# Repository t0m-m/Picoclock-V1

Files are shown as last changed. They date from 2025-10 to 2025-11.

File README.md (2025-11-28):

# Picoclock-V1

Simple desktop clock built around the Raspberry Pi Pico and a custom PCB.

# Overview

Picoclock-V1 is a prototype designed for feature testing.
The final version will showcase vintage VQB-71 7-segment displays, but all other elements will remain the same.

The board includes:

* DS3231 high-accuracy real-time clock

* MAX7221 display driver

* Buzzer for alarm

* Four control buttons for brightness, confirm, cancel, and mode selection

Currently, the unit does not include an onboard battery and requires external power via the Pico’s micro-USB port.
A future version may include a Li-ion battery pack for standalone operation.

# Implemented Features

* Time keeping

* Date display mode

* Alarm mode

* Hardware

Initially planned as a 2-layer PCB, the design evolved into a 4-layer board for cleaner signal routing and improved performance.
The board also includes four 3 mm mounting holes for attaching a plexiglass cover or securing the unit in place.

# Notes

This version focuses on functionality and layout validation. The next iteration will aim for improved aesthetics, enclosure design, and power management.



# Update - 12.11.2025

Boards and components finally arrived! Multimeter testing came out very promising. Soldering soon.



# Update 24.11.2025

Unfortunately there has been a mistake in the board files, the pins for the SPI were routed incorrectly. Luckily I have managed to fix the issue with external cables. I have updated the board files to the correct version. Below is the picture of working board. I am working on software, but basic functionality has been implemented.



https://github.com/user-attachments/assets/9fb4b469-f7aa-4e1a-90d6-b6b4e3de2fa9

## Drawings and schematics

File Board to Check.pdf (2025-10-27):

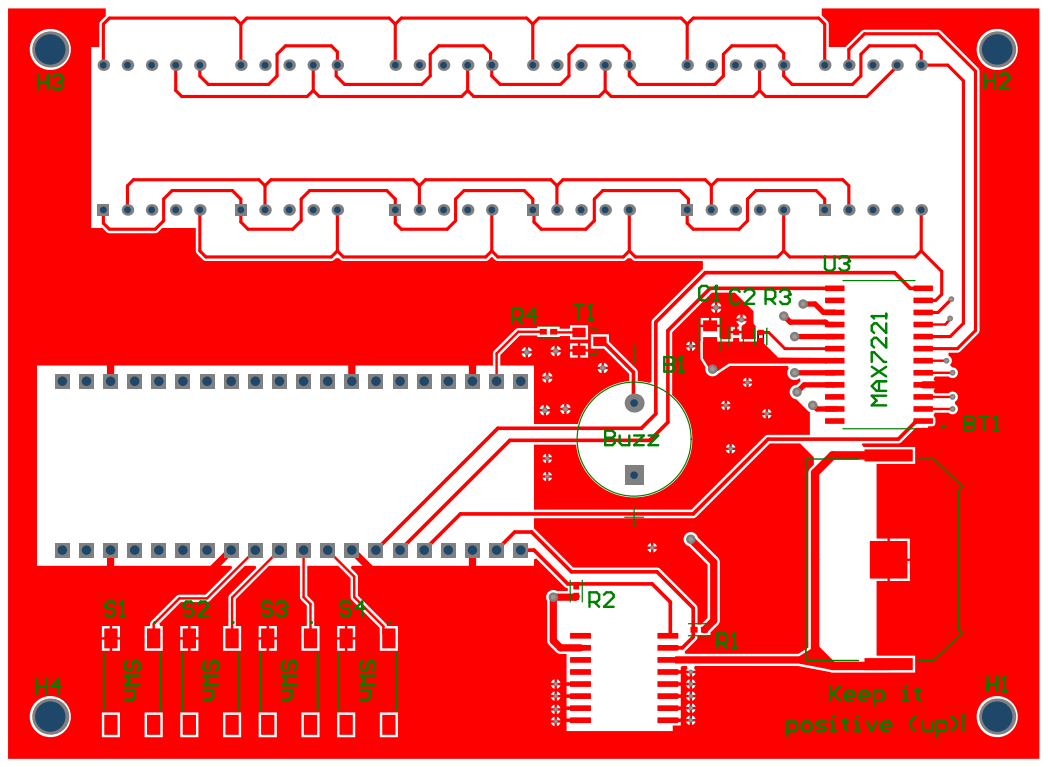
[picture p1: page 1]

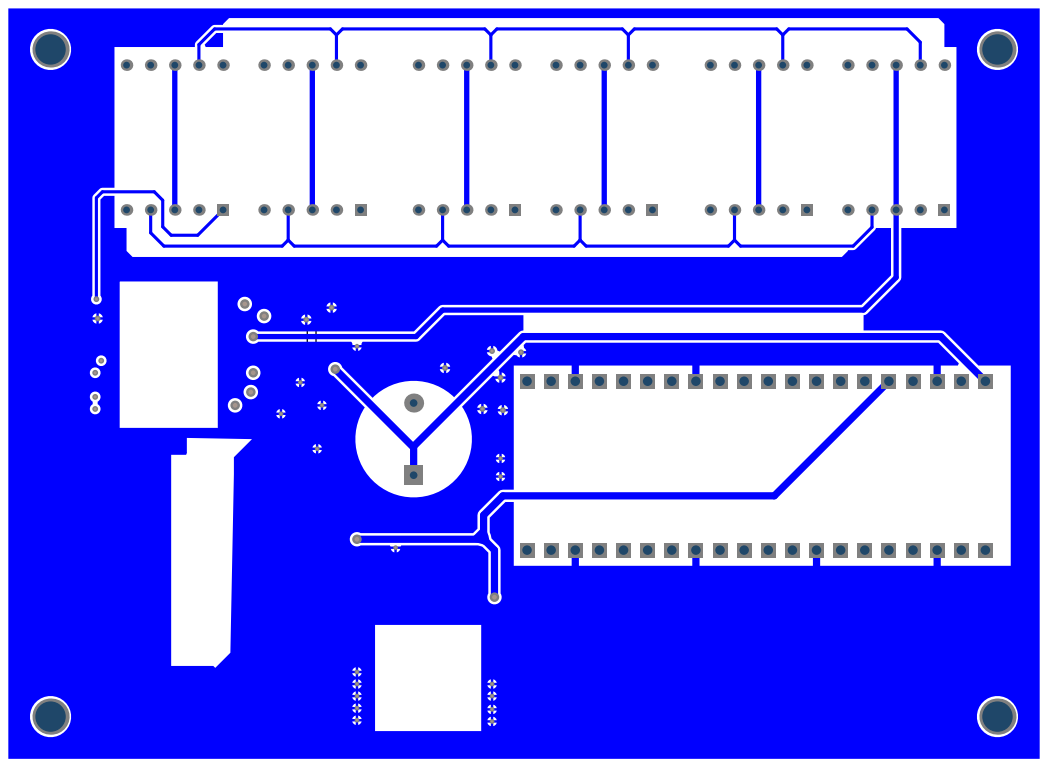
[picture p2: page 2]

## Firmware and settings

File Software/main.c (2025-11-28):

#include <stdio.h>
#include "pico/stdlib.h"
#include "hardware/spi.h"
#include "hardware/timer.h"
#include "hardware/i2c.h"
#include "pico/binary_info.h"

// PINY SPI
#define PIN_CS   13
#define PIN_SCK  10
#define PIN_MOSI 11

// PINY I2C
#define PIN_SDA 14
#define PIN_SCL 15

// PINY PRZYCISKOW
#define BUTTON_PIN 6
#define BUTTON_PIN2 7
#define BUTTON_PIN3 8
#define BUTTON_PIN4 9

// MAX 7221 
//void max7221_send(uint8_t addr, uint8_t data) {   // MAX oczekuje danych, 8 bitow adresu i 8 bitow danych
//    gpio_put(PIN_CS, 0);                          // aktywujemy CS, zeby MAX wiedzial ze do niego wysylamy, CS = 0 <- wysylamy, CS = 1 <- MAX przestaje odbierac i wykonuje komende
//    uint8_t buf[2] = { addr, data };              // 16 bitow, adres + data
//    spi_write_blocking(spi1, buf, 2);             // po sp1 wyslij z tablicy buf 2 wartosci pod kolejnymi jej adresami. blocking oznacza ze czeka az wszystkie dane zostana wyslane
//   gpio_put(PIN_CS, 1);                          // ustawiamy CS na wartosc 1, zeby MAX wykonal polecenia ktore mu dalismy
//}

//void max7221_init() {
//    max7221_send(0x09, 0x00);  // decode off
//    max7221_send(0x0A, 0x05);  // intensity
//    max7221_send(0x0B, 0x07);  // scan limit = 6
//    max7221_send(0x0C, 0x01);  // normal operation
//    max7221_send(0x0F, 0x00);  // display test off
//}

// I2C ADDRESS RESERVATION
bool reserved_addr(uint8_t addr) {                        // Funkcja sprawdza czy specjalne adresy i2c nie sa zarezerwowane 
    return (addr & 0x78) == 0 || (addr & 0x78) == 0x78;   // Specjalne adresy sa od 000 0xxx do 111 1xxx
}

// DS 3231
void ds3231_set_time(uint8_t *buf) {
    uint8_t start = 0x00; 
    i2c_write_blocking(i2c1, 0x68, &start, 1, true);
    i2c_write_blocking(i2c1, 0x68, buf, 7, false);
}

void ds3231_read_time(uint8_t *buf) {
    uint8_t start = 0x00;                                // 0x68 to adres i2c urzadzenia DS3231
    i2c_write_blocking(i2c1, 0x68, &start, 1, true);     // Funkcja ustawia bajt od ktorego chce czytac na 1
    i2c_read_blocking(i2c1, 0x68, buf, 7, false);        // Funkcja zczytuje wartości od 0x00 do 0x06, czyli sekundy, minuty, godziny, dzien tygodnia, dzien miesiaca, miesiac, rok 
}

void ds3231_init() {
    uint8_t EOSC = 0x0E;
    uint8_t reg;

    i2c_write_blocking(i2c1, 0x68, &EOSC, 1, true);
    i2c_read_blocking(i2c1, 0x68, &reg, 1, false);

    reg &= 0b00111111;

    i2c_write_blocking(i2c1, 0x68, &EOSC, 1, true);
    i2c_write_blocking(i2c1, 0x68, &reg, 1, false);
}

int bcd_to_int(uint8_t bcd) {                           // Funkcja ktora zamiaenia BCD na integer
    return ((bcd >> 4) * 10) + (bcd & 0x0F);            
}

// MAPA SEGMENTOW
// Segmenty: C DP A F G E D B   (nie wiem co tu sie odjebalo ale tak jest)
//const bool digit_segments[10][8] = {
//    {1,0,1,1,0,1,1,1}, // 0
//    {1,0,0,0,0,0,0,1}, // 1
//    {0,0,1,0,1,1,1,1}, // 2
//    {1,0,1,0,1,0,1,1}, // 3
//    {1,0,0,1,1,0,0,1}, // 4
//    {1,0,1,1,1,0,1,0}, // 5
//    {1,0,1,1,1,1,1,0}, // 6
//    {1,0,1,0,0,0,0,1}, // 7
//    {1,0,1,1,1,1,1,1}, // 8
//    {1,0,1,1,1,0,1,1}, // 9
//};

// WYSWIETLANIE LICZB Z ZAMIENIONYMI DIG I SEG
void display_digits_swapped(const int *digits, int count) {
    uint8_t segment_masks[8] = {0};

    for (int pos = 0; pos < count; pos++) {
        int d = digits[pos];
        for (int seg = 0; seg < 8; seg++) {
            if (digit_segments[d][seg])
                segment_masks[seg] |= (1u << pos);
        }
    }

    for (int seg = 0; seg < 8; seg++)
        max7221_send(seg + 1, segment_masks[seg]);
}

// ZMIENNE CZASU
//int hours = 1;
//int minutes = 16;
//int seconds = 0;

// ZMIENNA JASNOSCI
uint8_t brightness = 0;

// TIMER 1S 
int64_t tick() {
    int digits[6];
    uint8_t buf1[7];
    int sec, min, hour;

    ds3231_read_time(buf1);       // Funkcja zczytuje czas z DSa
    sec = bcd_to_int(buf1[0]);    
    min = bcd_to_int(buf1[1]);
    hour = bcd_to_int(buf1[2]);   // Konwersja z BCD na inty tak aby MAX mogl to zrozumiec

    digits[0] = hour / 10;
    digits[1] = hour % 10;
    digits[2] = min / 10;
    digits[3] = min % 10;
    digits[4] = sec / 10;
    digits[5] = sec % 10;

    display_digits_swapped(digits, 6);

    return 1000000; // wywołuj co 1 sekundę
}

// PRZYCISK
void init_button() {
    gpio_init(BUTTON_PIN);
    gpio_set_dir(BUTTON_PIN, GPIO_IN);
    gpio_pull_up(BUTTON_PIN);
}

// SPRAWDZ CZY PRZYCISK WCISNIEY + DEBOUNCER
bool button_pressed() {
    static uint32_t last_time = 0;

    if (!gpio_get(BUTTON_PIN)) {
        uint32_t now = to_ms_since_boot(get_absolute_time());
        if (now - last_time > 250) {
            last_time = now;
            return true;
        }
    }
    return false;
}

// KONTROLA JASNOCI
void update_brightness() {
    brightness += 2;
    if (brightness > 11) brightness = 0;
    max7221_send(0x0A, brightness);
}

int main() {                              // DS 3231 oczekuje od nas danych w formacie BCD, czyli np. 23 w dziesietnym = 0x23 w BCD
    uint8_t time_set[7] = {               // tablica w ktorej ustawiamy pierwotny czas 
        {0x00},                           // sekundy
        {0x00},                           // minuty
        {0x12},                           // godziny
        {0x01},                           // dzien tygodnia od 1 do 7, na razie ustawiony poniedzialek
        {0x25},                           // dzien miesiaca
        {0x11},                           // miesiac, na razie ustawiony listopad
        {0x25},                           // rok 
    };

    uint8_t kropki = (1 << 1) | (1 << 3); // Wyswietla kropki HH. MM. SS
    stdio_init_all();
    
    // SPI1 init
    spi_init(spi1, 4000000);
    gpio_set_function(PIN_MOSI, GPIO_FUNC_SPI);
    gpio_set_function(PIN_SCK,  GPIO_FUNC_SPI);

    gpio_init(PIN_CS);
    gpio_set_dir(PIN_CS, GPIO_OUT);
    gpio_put(PIN_CS, 1);

    // I2C init
    i2c_init(i2c1, 400 * 1000);                  // Uzywamy i2c1 i baudrate ustawiony na 100kHz
    gpio_set_function(PIN_SDA, GPIO_FUNC_I2C);   // Przypisanie funkcji odpowiednim pinom
    gpio_set_function(PIN_SCL, GPIO_FUNC_I2C);

    gpio_pull_up(PIN_SDA);                       // Aktywowane pull upy na liniach SDA i SCL 
    gpio_pull_up(PIN_SCL);

    // DS 3231 write time
    ds3231_init();
    //ds3231_set_time(time_set);
    
    // MAX 7221 init
    max7221_init();

    // Button init5
    init_button();
    

    // Timer 1 sekunda
    add_alarm_in_ms(1000, tick, NULL, true);       // to jest funkcja callback, ktora odswieza sie automatycznie co 1000ms, czyli co sekunde czas sie aktualizuje

    while (1) {
        tight_loop_contents();
        max7221_send(2,kropki);
        if (button_pressed()) {
            update_brightness();
        }
    }
}

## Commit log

2025-11-24 Changed the SPI pins to correct ones on Pico
    [Main.SchDoc, PCB2.PcbDoc]
2025-11-24 Updated prodution files
    [PCB2.GBL, PCB2.GBS, PCB2.GTL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]
2025-11-24 Prototype Software
2025-11-24 Software prototype
2025-11-28 Updated structure
    [Main.SchDoc, PCB2.PcbDoc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]
